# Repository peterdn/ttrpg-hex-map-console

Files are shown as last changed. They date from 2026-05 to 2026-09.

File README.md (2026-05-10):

# ttrpg-hex-map-console

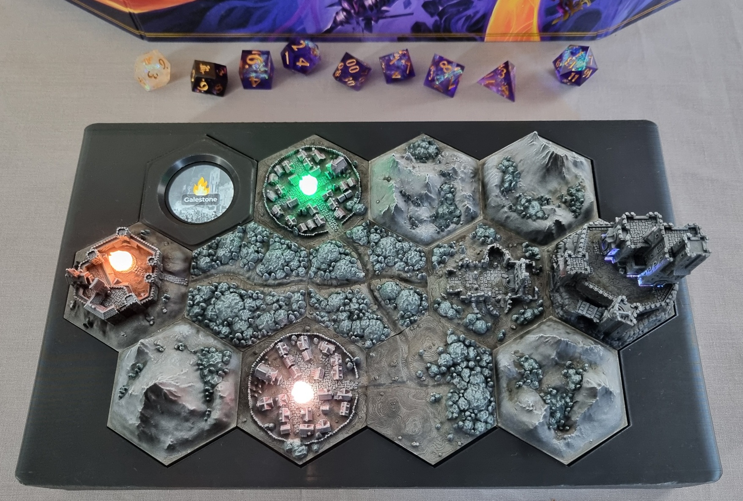
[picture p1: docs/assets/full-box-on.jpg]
Photo of the Age of Umbra console on a gaming table with Daggerheart dice and DM screen for scale


## Overview and background

This repo contains the software, schematics, and 3D-printable models for the physical interactive hex map "console" I built for my [Daggerheart: Age of Umbra](https://www.daggerheart.com/umbra/) campaign.

In the Age of Umbra campaign setting, communities gather around Sacred Pyres: beacons of hope in an otherwise bleak and desolate world. During a recent campaign I ran as DM, part of the storyline involved these Pyres becoming corrupted, extinguished, and relit anew. I wanted to build a physical prop that could represent the state of the world, including these pyres, as a player aid. And so this project was born.

The console includes a 3D hex map of the small corner of the Halcyon Domain in which my campaign ran. Four LEDs, connected to an ESP32-S3 touchscreen dev board, represent the Pyres and other atmospheric lighting within the map. The touchscreen device itself is integrated into a hex tile in the top left corner of the console. To reflect what happens in-game as it happens, Pyres may be extinguished or corrupted using the touchscreen or wirelessly using an HTTP API that the ESP32-S3 software serves.

## Features

- 🔥 LED "Pyres" with flicker and transition effects.
- 📱 [Waveshare ESP32-S3-Touch-LCD-1.28](https://www.waveshare.com/wiki/ESP32-S3-Touch-LCD-1.28) device embedded in the hex map provides touchscreen controls for each Pyre.
- 🌐 An HTTP API enables wireless control of each Pyre, as well as battery/power information.
- 🔋 Power is provided by an internal Li-Ion battery that can be charged via a USB-C port.
- 🏔️ 3D-printed and hand-painted hex map tiles (models by [Hexton Hills](https://www.hextonhills.com/)).
- 📦 3D-printed enclosure:
  - Separate body and lid, assembled together using screws.
  - USB-C port.
  - Slide switch to power on/off.

## Repo structure

This repo contains the following materials, please see individual READMEs for more details:

- docs/ -- miscellaneous documentation and photos.
- electronics/ -- schematics for the ESP32-S3, GPIO, LEDs, and associated electronic circuitry.
- firmware/ -- the software that runs on the ESP32-S3, including patches for the base MicroPython firmware, and the touchscreen app.
- hardware/ -- models and details of the 3D-printed hardware.

## License and contributing

This project is MIT licensed. Feel free to use and adapt whatever parts of it for your own TTRPG campaign.

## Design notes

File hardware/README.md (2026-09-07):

# Hardware

This directory contains the custom-designed and specialised 3D assets for the project.

## File guide

- enclosure/
  - body.stl -- the main body of the console. Includes mounting points for the assembled hex map grid, holes for LEDs and the ESP32-S3 in the top, and holes for a female USB-C adapter and slide switch in the side.
  - lid.stl -- the back lid of the console. Secured to the body using 10x 16mm M2 self tapping round head screws.
- hex-map/
  - display-hex.stl -- the hex body within which the [Waveshare ESP32-S3-Touch-LCD-1.28](https://www.waveshare.com/wiki/ESP32-S3-Touch-LCD-1.28) device sits, and a restraining bar that screws into place using 2x 10mm M2 self tapping round head screws.
  - flame.stl -- the flame-shaped cap that sits over LEDs. Printed in clear/transparent plastic for obvious reasons.
  - hexton-hills - Age of Umbra.json -- BOM of Hexton Hills tiles for the hex map. View using the [Hexton Hills Map Planner](https://map.hextonhills.com/).
  - hexton-hills - Age of Umbra.png -- export of the hex tile map from the Hexton Hills Map Planner.

## 3D printing notes

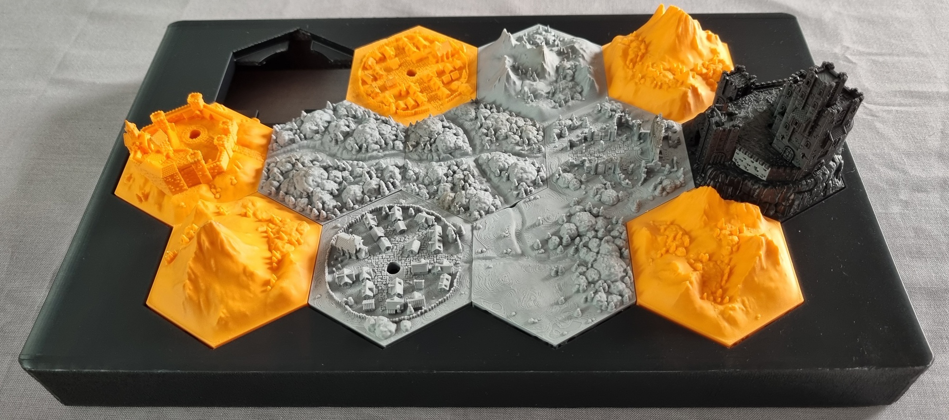
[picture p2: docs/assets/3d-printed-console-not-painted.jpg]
Partially assembled and unpainted Age of Umbra console, showing the different FDM colours that were used to print the hex tiles.


**Hex tiles**

- Printer: Bambu Lab A1 (FDM).
- Settings: 0.08mm "high quality".
- Filament: Bambu PLA Matte Grey/Orange, Elegoo Rapid PLA+ Black.
- Notes: Since I painted the tiles, the underlying colour did not matter so much EXCEPT for the hollowed-out castle, where the orange colour would bleed through. I reprinted this in black for the final piece.

**Enclosure**

- Printer: Bambu Lab A1 (FDM).
- Settings: 0.20mm "standard", modified as below for the main body printed on its side.
- Filament: Elegoo Rapid PLA+ Black.
- Notes: The body was printed in one piece on its side, arranged diagonally across the build plate. Despite lowering nozzle speeds and other settings (see table below) to prevent vibrations from affecting the print as it grew taller, there was some "wavy" artifacting on the top edge. Ideally one would use a printer with a sufficiently large build plate to print this flat. I judged that the lid would be far too precarious to print on its side, so I had to print it flat in two pieces.

| Page | Section | Setting | Value |
| --- | --- | --- | --- |
| Others | Brim | Brim type | Outer brim only |
| Others | Brim | Brim width | 15mm |
| Speed  | Other layers speed | Outer wall | 60mm/s |
| Speed  | Other layers speed | Inner wall | 120mm/s |
| Speed  | Other layers speed | Gap infill | 100mm/s |
| Speed  | Other layers speed | Support | 120mm/s |
| Speed  | Travel speed | Travel | 250mm/s |
| Speed  | Acceleration | Normal printing | 3000mm/s<sup>2</sup> |
| Speed  | Acceleration | Outer wall | 2000mm/s<sup>2</sup> |
| Speed  | Acceleration | Travel | 3000mm/s<sup>2</sup> |

**Flame caps**

- Printer: Elegoo Mars 3 Pro (SLA).
- Settings: 0.05mm layer height, 7s layer exposure.
- Resin: Anycubic High Clear.
- Notes: I purposefully did not follow the advice to "clear up" the prints post-processing, leaving them frosty instead of fully transparent. This nicely diffuses the bright LED light.

## Painting notes

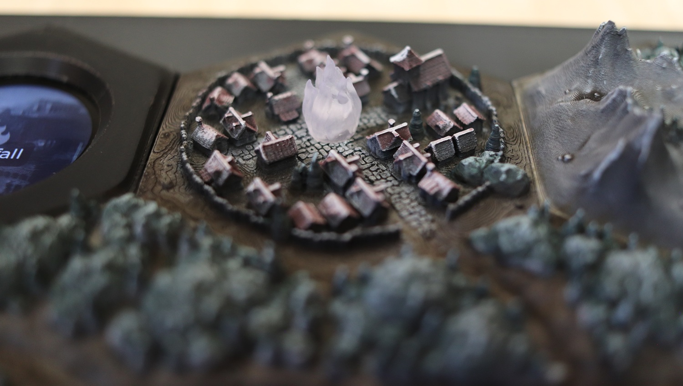
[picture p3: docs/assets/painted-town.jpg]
Closeup photo of a town hex tile, surrounded by mountain and forest, its Pyre extinguished.


My goal was to capture the desaturated and bleak tone of the Age of Umbra setting by depicting the world illuminated by moonlight. My rough recipe was:

**Basecoat**

- Strong zenithal prime (white over black) from north only, to simulate moonlight from that direction.

**Ground**

- Mummified Grime (Army Painter Speedpaint 2.0).

**Mountains and stone buildings**

- Nuln Oil wash (Citadel).
- Light drybrush highlight with a mix of Fenrisian Grey (Citadel) + White (Vallejo), in the direction of the light.

**Trees and foliage**

- Gunner Camo (Army Painter Speedpaint 2.0).
- Rough highlight with a mix of Fenrisian Grey + White + Gunner Camo, in the direction of the light.

**Town roofs**

- Goddess Glow (Army Painter Speedpaint 2.0), trying to leave areas in shadow as pure black.
- Initial rough highlight with a mix of Fenrisian Grey + White + Goddess Glow, in the direction of the light.
- Final bright highlight of White + tiny amount of Fenrisian Grey on edges that would catch moonlight.

**Final**

- Airbrush varnish with Vallejo Matt Varnish.

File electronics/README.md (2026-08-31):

# Electronics

This directory contains the schematics for the circuitry powering project.

## Bill of materials

1. [Waveshare ESP32-S3-Touch-LCD-1.28](https://www.waveshare.com/wiki/ESP32-S3-Touch-LCD-1.28): touchscreen and microcontroller that drives the console LEDs.
2. 4x common anode RGB LEDs: for the Pyres and other lighting.
3. TLC5947 24-channel 12-bit PWM LED driver module (CJMCU clone of the [Adafruit module](https://www.adafruit.com/product/1429)): allows the ESP32-S3 to drive multiple LEDs from only a few GPIO outputs.
4. MT3608 boost converter module: steps up the VSYS rail provided by the ESP32-S3 to 5V required by the TLC5947.
5. 3.7V 2000mAh 103454 LiPo Rechargeable Battery: powers the board for ~6-7 hours.
6. (Optional if battery doesn't already have one) 3.7V 3A Li-ion BMS PCM battery protection board: disconnects the cell if it charges too high or discharges too low.
7. MX 1.25 connector for battery to ESP32-S3.
8. Slide switch: to power console on/off.
9. USB-C 4-pin female chassis: USB port.
10. USB-C 4-pin male breakout board: connects ESP32-S3 USB-C to female chassis.
11. Wiring to connect everything up.

## Schematics

### Power to ESP32-S3

The LiPo battery connects to the ESP32-S3 board via the MX 1.25 connector. The slide switch is wired inline with the battery positive lead. The USB-C chassis port is extended from the board's onboard port via a male-to-female breakout.

**NOTE**: for the battery to charge, the slide switch must be in the ON position.

### GPIO to LEDs

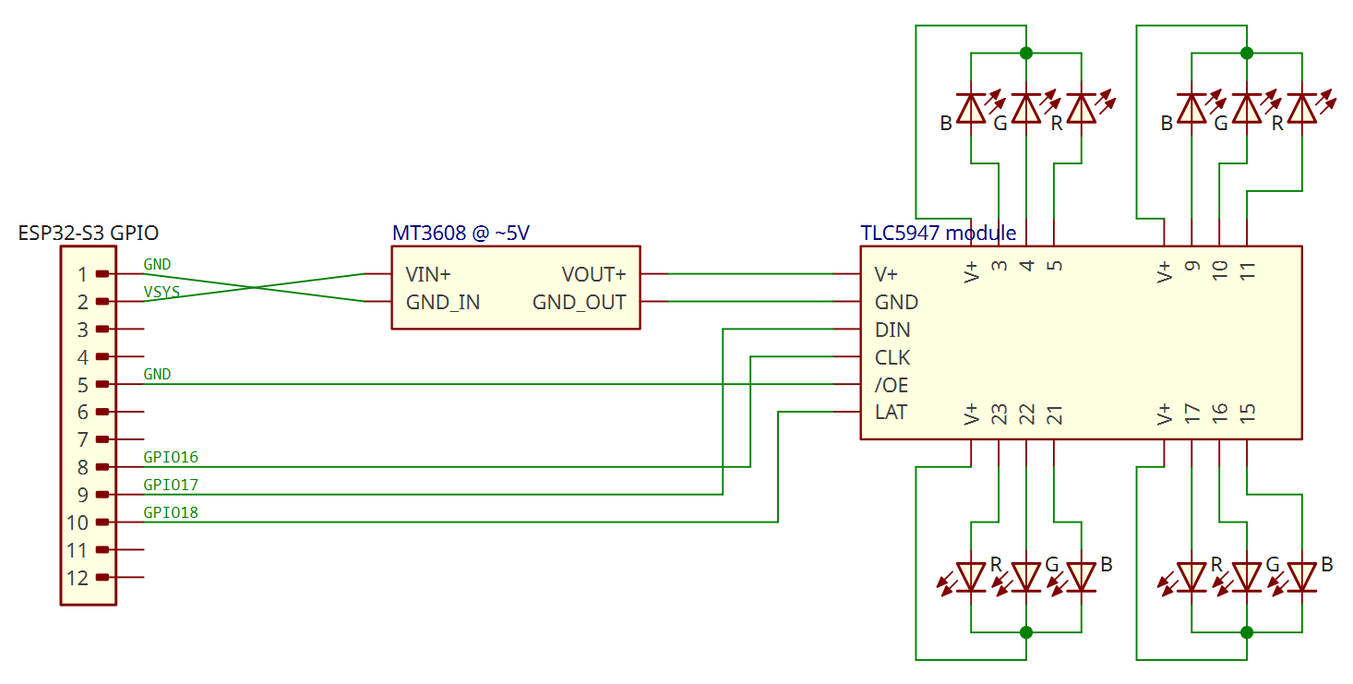
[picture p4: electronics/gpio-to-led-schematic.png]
Circuit diagram showing how LEDs connect from ESP32-S3 GPIO.


## Interior assembly

See photo for internal component layout within the enclosure. Liberal usage of hot glue ensures most components do not rattle about. Please forgive the "prototype quality"!!

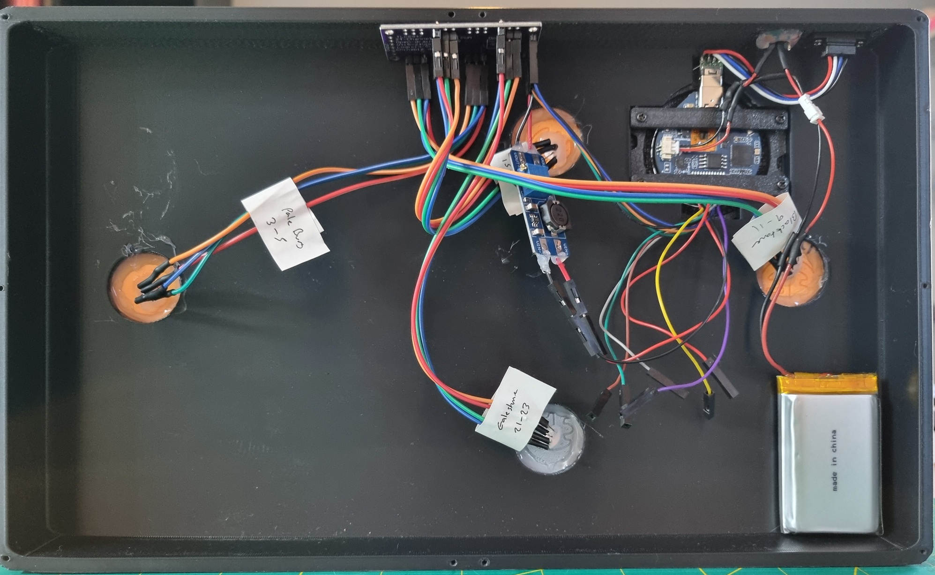
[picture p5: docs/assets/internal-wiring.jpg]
Photo of the internal wiring and component placement.


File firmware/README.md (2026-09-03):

# Firmware

This directory contains the software for the ESP32-S3 that powers the project.

## Software stack

The ESP32-S3 runs the following software stack:

1. Base firmware: custom build of [lv_micropython](https://github.com/lvgl/lv_micropython) (a [MicroPython](https://micropython.org/) fork that includes LVGL UI library).
2. GC9A01 display driver: [gc9a01_mpy](https://github.com/russhughes/gc9a01_mpy) built as a MicroPython user module.
3. User interface: [LVGL v9.3](https://github.com/lvgl/lvgl).
4. HTTP server and API: [Microdot](https://github.com/miguelgrinberg/microdot).

## Structure

- app/ -- source for the Age of Umbra application, including LVGL-compatible image files for the assets.
- assets/ -- original image assets.
- patches/ -- patches for lv_micropython and gc9a01_mpy to enable some required functionality and fix incompatibilities.
- tools/ -- scripts and tools for testing.

## Prerequisites

**ESP-IDF**

[ESP-IDF ESP32 toolchain](https://docs.espressif.com/projects/esp-idf/en/stable/esp32/get-started/index.html) [v5.2.2](https://github.com/espressif/esp-idf/tree/v5.2.2) (_specifically_) is required for building firmware for this device. Check out this version using:

```bash
git clone -b v5.2.2 --recursive https://github.com/espressif/esp-idf.git esp-idf-5.2.2
```

And follow the build instructions in that repo.

**mpremote**

[mpremote](https://docs.micropython.org/en/latest/reference/mpremote.html) is a MicroPython tool for interacting with a device over serial, including copying files, and Python REPL. Install it via pip:

```bash
pip install --user mpremote
```

## Custom MicroPython firmware

A custom firmware image was built using:

1. [lv_micropython](https://github.com/lvgl/lv_micropython) commit `acfeb7b7ead9eedc636d2d82c8a8d9908ea5ffac`.
2. [gc9a01_mpy](https://github.com/russhughes/gc9a01_mpy) commit `6ceba791a462bc5764d8340c2af0d0c3f77fb4d3`.

**Check out lv_micropython and apply patch**

This patch is required to set a few build configurations (including the `LV_COLOR_DEPTH=16` and `LV_COLOR_16_SWAP=1` LVGL flags, which the GC9A01 needs), and enable the use of MicroPython's SoftSPI without specifying MISO pin, as we want to use this to drive the TLC5947 LED driver but it is a write-only device.

From within `firmware` directory:

```bash
git clone https://github.com/lvgl/lv_micropython.git lvmp
cd lvmp
git checkout acfeb7b7ead9eedc636d2d82c8a8d9908ea5ffac
git apply ../patches/lv_micropython/lvmp.patch
```

**Check out gc9a01_mpy and apply patch**

This patch is required to disable linking of `tjpg` library to avoid conflicts with it already linked into MicroPython.

From within `firmware` directory:

```bash
git clone https://github.com/russhughes/gc9a01_mpy.git
cd gc9a01_mpy
git checkout 6ceba791a462bc5764d8340c2af0d0c3f77fb4d3
git apply ../patches/gc9a01_mpy/gc9a01mpy.patch
```

**Build the firmware image**

From within `firmware` directory:

```bash
cd lvmp
git submodule update --init --recursive user_modules/lv_binding_micropython
make -C mp-cross
cd ports/esp32
make USER_C_MODULES=../../../gc9a01_mpy/src/micropython.cmake BOARD=ESP32_GENERIC_S3 all
```

**Flash the firmware**

From within the `firmware` directory, erase and flash the new firmware:

```bash
esptool.py --chip esp32s3 --port <PORT> erase_flash
esptool.py --chip esp32s3 --port <PORT> write_flash -z 0x0 lvmp/ports/esp32/build-ESP32_GENERIC_S3/firmware.bin
```

## Age of Umbra app

**Set WiFi credentials**

Rename the template configuration file from `config.json.template` to `config.json` and enter your WiFi credentials so the device can connect.

**FIXME**: the app is liable to hang if it is unable to connect to WiFi.

**Install app**

To install the app on an ESP32-S3, copy the entire contents of `app/` to the root of the device using `mpremote`:

```bash
mpremote connect <PORT> fs cp -r app/. :
```

## Tools

**serve_http_app.py**

This runs the Microdot HTTP server locally for testing. It mocks out various device-specific functionality. Run it from the `firmware` directory:

```bash
export PYTHONPATH=$PYTHONPATH:$(pwd)/app
python -m tools.serve_http_app
```

Access the app at http://localhost:5000.

## Assets

Original images live in `assets/` as PNGs. They are pre-converted into LVGL's binary format in `app/assets/` for deployment to the device.

### Converting assets to LVGL .bin format

Use the [LVGLImage.py](https://github.com/lvgl/lvgl/blob/master/scripts/LVGLImage.py) tool within `lvmp/user_modules/lv_binding_micropython/lvgl/scripts`.

From within the `firmware` directory:

```bash
pip install -r lvmp/user_modules/lv_binding_micropython/lvgl/scripts/prerequisites-pip.txt
```

**Full-screen images**: town backgrounds and the splash screen convert to `RGB565` format (no transparency). For example:

```bash
python lvmp/user_modules/lv_binding_micropython/lvgl/scripts/LVGLImage.py --ofmt BIN --cf RGB565 -o app/assets/ assets/galestone.png
```

**Flame icons** are drawn on top of the background and need an alpha channel to preserve transparency, so convert these to `RGB565A8` format. For example:

```bash
python lvmp/user_modules/lv_binding_micropython/lvgl/scripts/LVGLImage.py --ofmt BIN --cf RGB565A8 -o app/assets/ assets/flame_everburning.png
```

### Attribution

- age_of_umbra.png -- from Darrington Press Daggerheart Age of Umbra mini-series, 2025 [announcement](https://darringtonpress.com/daggerheart-age-of-umbra-mini-series-coming-to-critical-role-may-29th/) (fair use).
- blacktower.png -- from "Chepstow Castle" by artist John Martin, [painted 1815](https://commons.wikimedia.org/wiki/File:John_Martin_-_Moonlight_-_Chepstow_Castle_-_Google_Art_Project.jpg).
- flame\_\* -- from [Flames SVG free download](https://svgcrown.com/download.php?category=flames&id=1) @ svgcrown.com.
- galestone.png -- from "Festivities in Windsor Castle" by artist Paul Sandby, [painted 1776](https://en.wikipedia.org/wiki/Guy_Fawkes_Night#/media/File:Windsor_castle_guyfawkesnight1776.jpg)
- paleburg.png -- from [Daggerheart Core Rulebook](https://www.daggerheart.com/buy/) p280 Chapter 5: The Age of Umbra, 2025 (fair use).
- ransfall.png -- from "Ruins of an Ancient City" by artist John Martin, [painted between 1810-1820](https://artsandculture.google.com/asset/ruins-of-an-ancient-city-john-martin-british-1789%E2%80%931854/dAHVu0DaiYAoIg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).

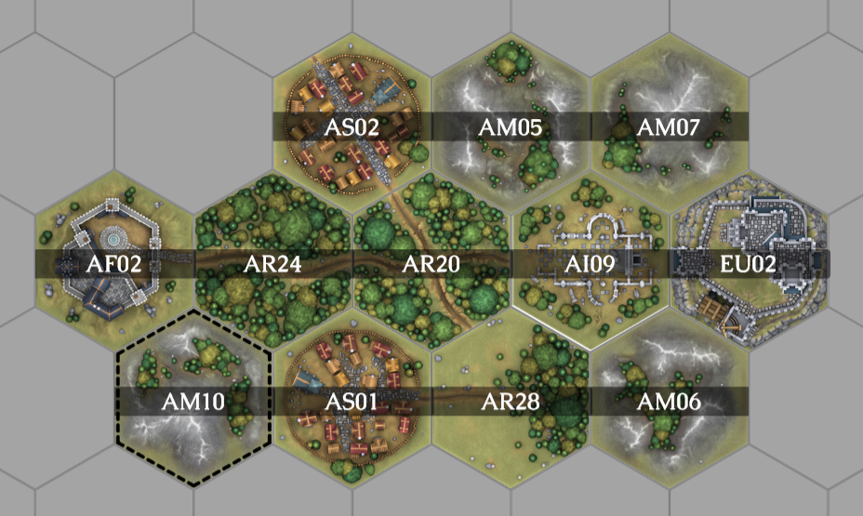
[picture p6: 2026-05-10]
hardware/hex-map/hexton-hills - Age of Umbra.png

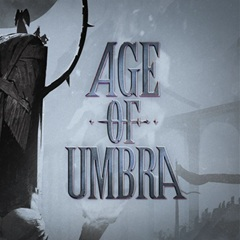
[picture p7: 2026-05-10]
firmware/assets/age_of_umbra.png

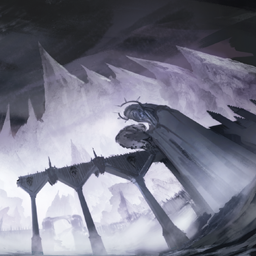
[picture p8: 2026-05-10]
firmware/assets/paleburg.png

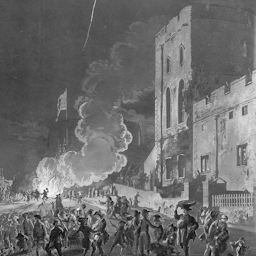
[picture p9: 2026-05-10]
firmware/assets/galestone.png

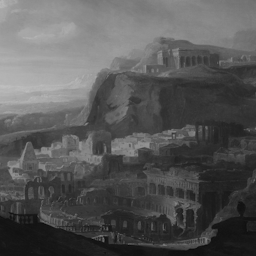
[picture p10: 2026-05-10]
firmware/assets/ransfall.png

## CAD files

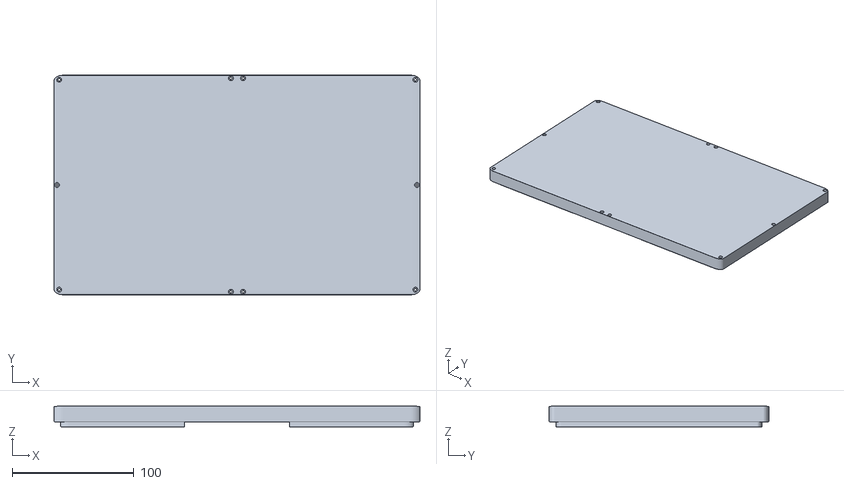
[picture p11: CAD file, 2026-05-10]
hardware/enclosure/lid.stl
300.0 x 180.0 x 17.0

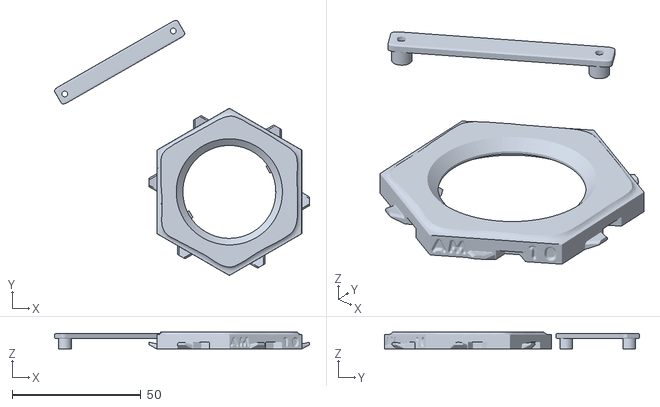
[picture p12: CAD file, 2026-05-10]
hardware/hex-map/display-hex.stl
99.1 x 99.1 x 6.54

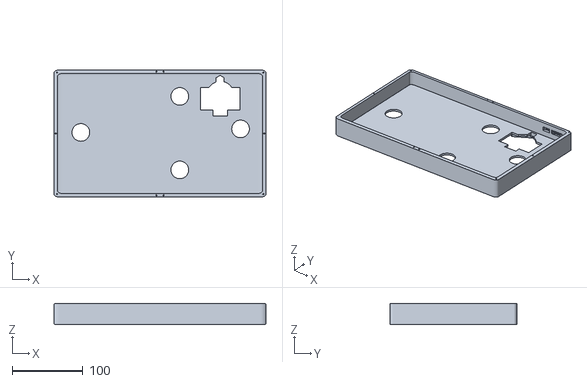
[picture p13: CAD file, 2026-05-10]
hardware/enclosure/body.stl
300.0 x 180.0 x 30.0

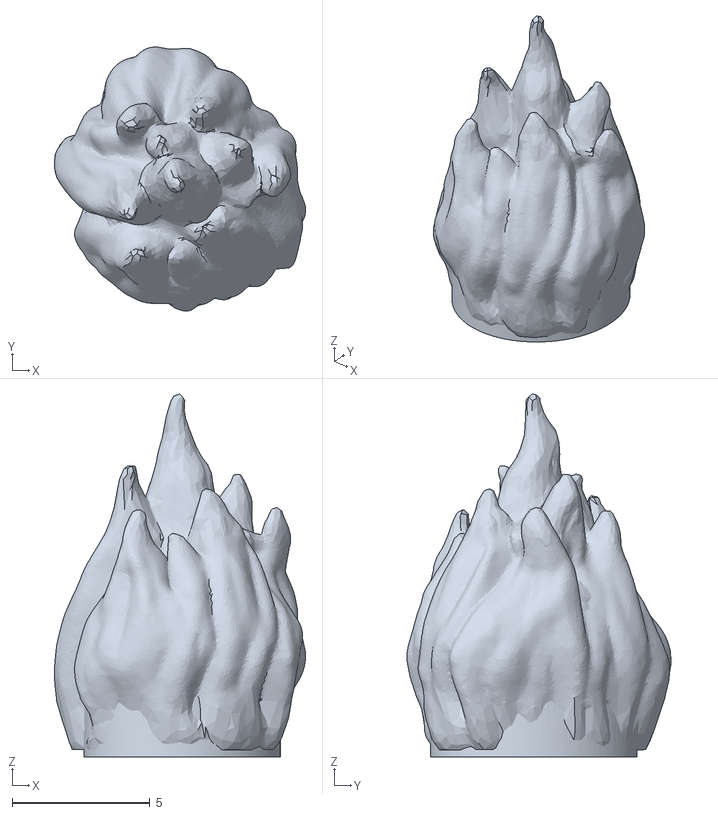
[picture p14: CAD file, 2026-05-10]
hardware/hex-map/flame.stl
9.10 x 9.57 x 13.2

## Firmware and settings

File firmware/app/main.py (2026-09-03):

import asyncio
import gc
from machine import Pin, SPI

import gc9a01_drv
from battery import BatteryState
from cachefs_drv import CacheFS
from config import Config
from cst816s_drv import CST816S
from game_state import GameState
from http_app import HttpApp
from tlc5947 import TLC5947
from ui import UserInterface, ui_task
from wifi import connect_to_wifi

gc.enable()
gc.collect()


async def main():
    # set up display
    spi = SPI(2, baudrate=80000000, polarity=0, sck=Pin(10), mosi=Pin(11))
    display = gc9a01_drv.GC9A01(
        spi, 240, 240, reset=14, cs=9, dc=8, backlight=2, rotation=2
    )
    display.fill(gc9a01_drv.BLACK)

    # set up touch input
    cst816s = CST816S(scl=7, sda=6, rst=13, mirror_x=True, mirror_y=True)

    print("Device setup complete!")

    # set up file system and cache
    # NOTE: the variable is unused but the object sets up some global LVGL state
    cache_fs = CacheFS(cache_size=32768)

    tlc5947 = TLC5947(clk_pin=16, data_pin=17, latch_pin=18, freq=400000)

    battery_state = BatteryState()

    game_state = GameState()

    ui = UserInterface(cst816s, tlc5947, game_state, battery_state)

    config = Config("config.json")

    http_app = HttpApp(game_state, battery_state)

    server = asyncio.create_task(http_app.start_server())
    wifi_task = asyncio.create_task(
        connect_to_wifi(config.wifi_ssid, config.wifi_password, ui.wifi_connection_cb)
    )
    await asyncio.gather(ui_task(), server, wifi_task)


if __name__ == "__main__":
    asyncio.run(main())

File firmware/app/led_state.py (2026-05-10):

"""
LED state management and animation logic for:
- Flickering to simulate flame.
- Transitions between colours when fire states change.
"""

import random

from game_state import FireState
from ema import EMA


class HealthyFireLEDConfig:
    """Healthy fire is bright orange"""

    def __init__(self):
        self.base_color = (1.0, 0.41, 0)
        self.brightness_ema = EMA(0.1)
        self.red_jitter_ema = EMA(0.2)

    def tick(self):
        brightness = self.brightness_ema.update(random.random())
        red_jitter = self.red_jitter_ema.update(random.uniform(-0.1, 0.1))

        brightness = max(0.0, min(1.0, brightness + 0.3))

        r = brightness * (self.base_color[0] + red_jitter)
        r = max(0.0, min(1.0, r))
        g = brightness * (self.base_color[1] - red_jitter)
        g = max(0.0, min(1.0, g))
        b = brightness * self.base_color[2]
        b = max(0.0, min(1.0, b))

        return (r, g, b, brightness)


class ExtinguishedFireLEDConfig:
    """Extinguished fire is off"""

    def __init__(self):
        self.base_color = (0.0, 0.0, 0.0)

    def tick(self):
        return (0.0, 0.0, 0.0, 0.0)


class CorruptedFireLEDConfig(HealthyFireLEDConfig):
    """Corrupted fire is green"""

    def __init__(self):
        super().__init__()
        self.base_color = (0.0, 1.0, 0.0)


class EverburningFireLEDConfig(HealthyFireLEDConfig):
    """Everburning fire is bright golden white/yellow"""

    def __init__(self):
        super().__init__()
        self.base_color = (1.0, 0.9, 0.2)


class EtherealFireLEDConfig(HealthyFireLEDConfig):
    """Ethereal fire is blue"""

    def __init__(self):
        super().__init__()
        self.base_color = (0.2, 0.5, 1.0)


class LEDState:
    def __init__(
        self,
        name: str,
        channel: int,
        initial_fire_state: FireState = FireState.EXTINGUISHED,
    ):
        self.TRANSITION_TICKS = 20
        self.name = name
        self.channel = channel
        self._fire_state = initial_fire_state
        self.transition_ticks_remaining = 0

        self.led_configs = {
            FireState.HEALTHY: HealthyFireLEDConfig(),
            FireState.EXTINGUISHED: ExtinguishedFireLEDConfig(),
            FireState.CORRUPTED: CorruptedFireLEDConfig(),
            FireState.EVERBURNING: EverburningFireLEDConfig(),
            FireState.ETHEREAL: EtherealFireLEDConfig(),
        }

    def set_fire_state(self, fire_state: FireState):
        if fire_state == self._fire_state:
            return

        self._old_fire_state = self._fire_state
        self._fire_state = fire_state

        if self.transition_ticks_remaining == 0:
            self.transition_ticks_remaining = self.TRANSITION_TICKS
            self.transition_fire_values = self.led_configs[self._old_fire_state].tick()
        else:
            # a transition was already in progress, move the target without resetting the transition
            pass

    def tick(self):
        if self.transition_ticks_remaining > 0:
            # During a transition, interpolate between the old and new fire colours
            new_fire_values = self.led_configs[self._fire_state].tick()
            rdiff = new_fire_values[0] - self.transition_fire_values[0]
            gdiff = new_fire_values[1] - self.transition_fire_values[1]
            bdiff = new_fire_values[2] - self.transition_fire_values[2]
            brightness_diff = new_fire_values[3] - self.transition_fire_values[3]

            r = self.transition_fire_values[0] + rdiff / self.transition_ticks_remaining
            g = self.transition_fire_values[1] + gdiff / self.transition_ticks_remaining
            b = self.transition_fire_values[2] + bdiff / self.transition_ticks_remaining
            brightness = (
                self.transition_fire_values[3]
                + brightness_diff / self.transition_ticks_remaining
            )

            self.transition_ticks_remaining -= 1
            self.transition_fire_values = (r, g, b, brightness)
            return (r, g, b, brightness)
        else:
            # No transition in progress, just tick the current fire state config
            return self.led_configs[self._fire_state].tick()

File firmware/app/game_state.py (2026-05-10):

"""
Game state model that tracks:
- The current location displayed on the screen.
- The state of the fire at each location.

Notifies subscribed event handlers when game state changes.
"""


class FireState:
    EXTINGUISHED = 0
    HEALTHY = 1
    CORRUPTED = 2
    EVERBURNING = 3
    ETHEREAL = 4

    @staticmethod
    def is_valid(state):
        return state >= FireState.EXTINGUISHED and state <= FireState.ETHEREAL


class GameState:
    def __init__(self):
        self.locations = [
            "Galestone",
            "Ransfall",
            "Blacktower",
            "Pale Burg",
        ]
        self.fire_states = {loc: FireState.EXTINGUISHED for loc in self.locations}
        self.current_location = "Galestone"
        self.event_handlers = []

    def subscribe(self, event_handler):
        self.event_handlers.append(event_handler)

    def set_fire_state(self, location: str, state: int):
        if not FireState.is_valid(state):
            raise ValueError(f"Invalid fire state: {state}")
        if self.fire_states.get(location) != state:
            self.fire_states[location] = state
            self._dispatch_event("fire_state_change", location, state)

    def set_current_location(self, location: str):
        if location in self.locations and location != self.current_location:
            self.current_location = location
            self._dispatch_event(
                "location_change", location, self.fire_states[location]
            )

    def _dispatch_event(self, event_type, location, state):
        for handler in self.event_handlers:
            handler(event_type, location, state)

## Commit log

2026-05-10 Add code, models, schematics, assets
    [body.stl, display-hex.stl, flame.stl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]
2026-08-31 Fix OBOE in TLC5947 driver
    [tlc5947.py]
2026-09-03 Fix typo in TLC5947 class name
    [main.py, tlc5947.py, ui.py]
2026-09-07 Add custom print settings to README
